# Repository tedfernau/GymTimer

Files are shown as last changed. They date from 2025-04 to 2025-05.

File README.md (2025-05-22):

A simple timer with a button and a vibration motor. 

I was thinking of this as a way to time intervals during workouts, or for phone-free timing in the sauna.

I designed it for a belt holder, but then I realized I would never let anyone see this in public!

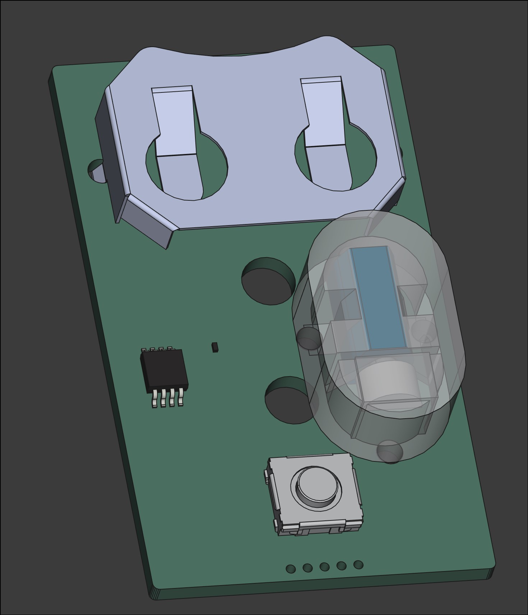
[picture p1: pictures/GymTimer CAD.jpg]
GymTimer GymTimer in FreeCAD


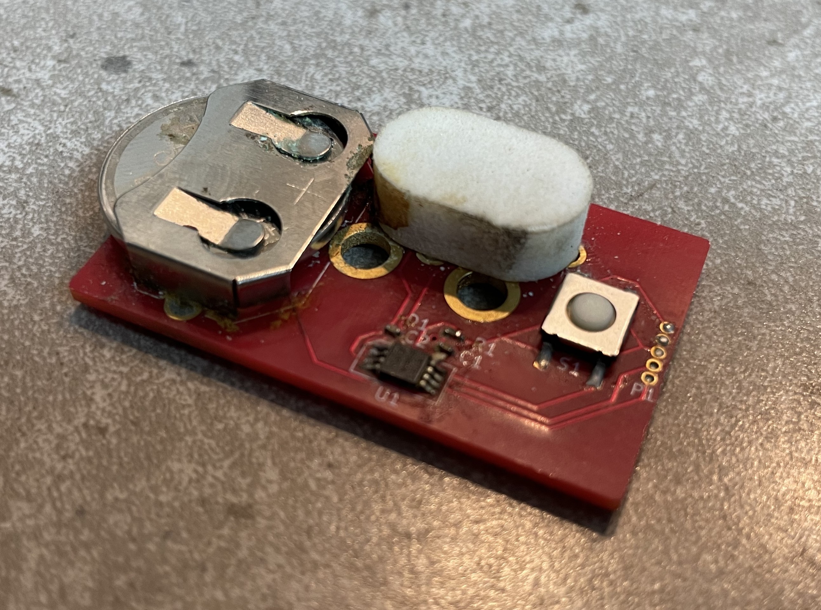
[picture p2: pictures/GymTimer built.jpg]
GymTimer GymTimer in FreeCAD


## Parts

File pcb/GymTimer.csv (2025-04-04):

Source: | C:\Users\fernau\OneDrive - F5, Inc\Desktop\LunchTimeProjects\GymTimer\GymTimer\pcb\GymTimer.kicad_sch
Date: | 5/27/2022 10:11:42 AM
Tool: | Eeschema (6.99.0-1656-g034b57d9c0)
Generator: | C:\Program Files\KiCad\6.99\bin\scripting\plugins/bom_csv_grouped_by_value.py
Component Count: | 8
Individual Components:
Item | Qty | Reference(s) | Value | LibPart | Footprint | Datasheet | Manufacturer Part Number
 |  | BT1 | BK-913 | GymTimer:BK-913 | GymTimer:BK-913 | https://www.digikey.com/en/products/detail/mpd-memory-protection-devices/BK-913/2329371
 |  | C1 | .1uF | Generic_Symbols:Capacitor | generic_footprints:cap-0402 | https://www.digikey.com/en/products/detail/kemet/C0402C104K4RACAUTO/3314827 | C0402C104K4RACAUTO
 |  | C2 | .1uF | Generic_Symbols:Capacitor | generic_footprints:cap-0402 | https://www.digikey.com/en/products/detail/kemet/C0402C104K4RACAUTO/3314827 | C0402C104K4RACAUTO
 |  | D1 | diode_TVS_bidirectional | Generic_Symbols:diode_TVS_bidirectional | GymTimer:TVS - PESD4V0Y1BSFYL | https://www.digikey.com/en/products/detail/nexperia-usa-inc/PESD4V0Y1BSFYL/9326494
 |  | M1 | VibrationDCmotor | GymTimer:VibrationDCmotor | GymTimer:Z4TH7B2120042P
 |  | R1 | 10k | Generic_Symbols:Resistor | generic_footprints:res_0402 | https://www.digikey.com/en/products/detail/koa-speer-electronics-inc/RK73G1ETTP1002F/9852052
 |  | S1 | SPST_NO_4pin | Generic_Symbols:SPST_NO_4pin | GymTimer:SPST-NO-EVQ-Q2U02W | https://www.digikey.com/en/products/detail/panasonic-electronic-components/EVQ-Q2U02W/762904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
 |  | U1 | PIC12F1571 | GymTimer:PIC12F1571 | GymTimer:PIC12F1571 MSOP8 | https://www.digikey.com/en/products/detail/microchip-technology/PIC12F1571-I-MS/4739306
Collated Components:
Item | Qty | Reference(s) | Value | LibPart | Footprint | Datasheet | Manufacturer Part Number
1 | 1 | BT1 | BK-913 | GymTimer:BK-913 | GymTimer:BK-913 | https://www.digikey.com/en/products/detail/mpd-memory-protection-devices/BK-913/2329371
2 | 2 | C1, C2 | .1uF | Generic_Symbols:Capacitor | generic_footprints:cap-0402 | https://www.digikey.com/en/products/detail/kemet/C0402C104K4RACAUTO/3314827 | C0402C104K4RACAUTO
3 | 1 | D1 | diode_TVS_bidirectional | Generic_Symbols:diode_TVS_bidirectional | GymTimer:TVS - PESD4V0Y1BSFYL | https://www.digikey.com/en/products/detail/nexperia-usa-inc/PESD4V0Y1BSFYL/9326494
4 | 1 | M1 | VibrationDCmotor | GymTimer:VibrationDCmotor | GymTimer:Z4TH7B2120042P
5 | 1 | R1 | 10k | Generic_Symbols:Resistor | generic_footprints:res_0402 | https://www.digikey.com/en/products/detail/koa-speer-electronics-inc/RK73G1ETTP1002F/9852052
6 | 1 | S1 | SPST_NO_4pin | Generic_Symbols:SPST_NO_4pin | GymTimer:SPST-NO-EVQ-Q2U02W | https://www.digikey.com/en/products/detail/panasonic-electronic-components/EVQ-Q2U02W/762904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
7 | 1 | U1 | PIC12F1571 | GymTimer:PIC12F1571 | GymTimer:PIC12F1571 MSOP8 | https://www.digikey.com/en/products/detail/microchip-technology/PIC12F1571-I-MS/4739306

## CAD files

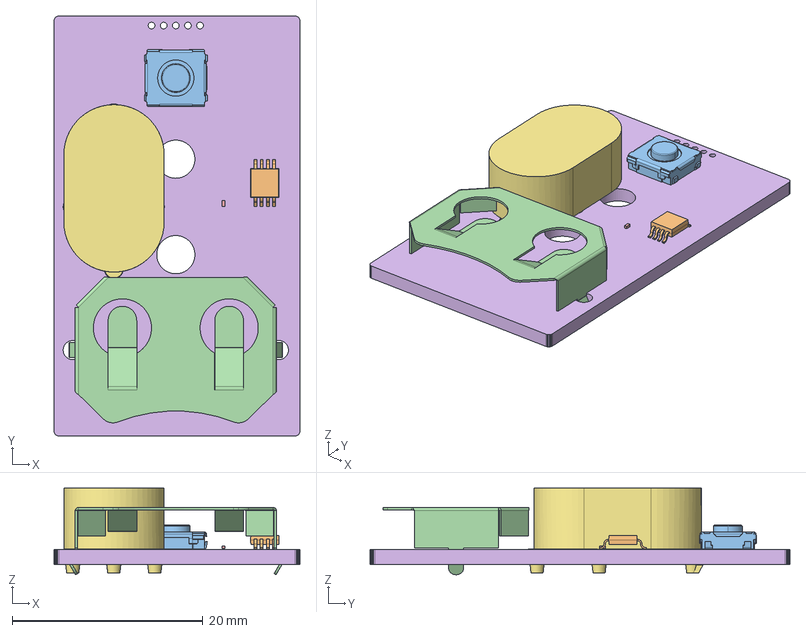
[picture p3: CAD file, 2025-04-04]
mechanical/Gymtimer.FCStd
25.8 x 44.0 x 9.07 mm
PCB

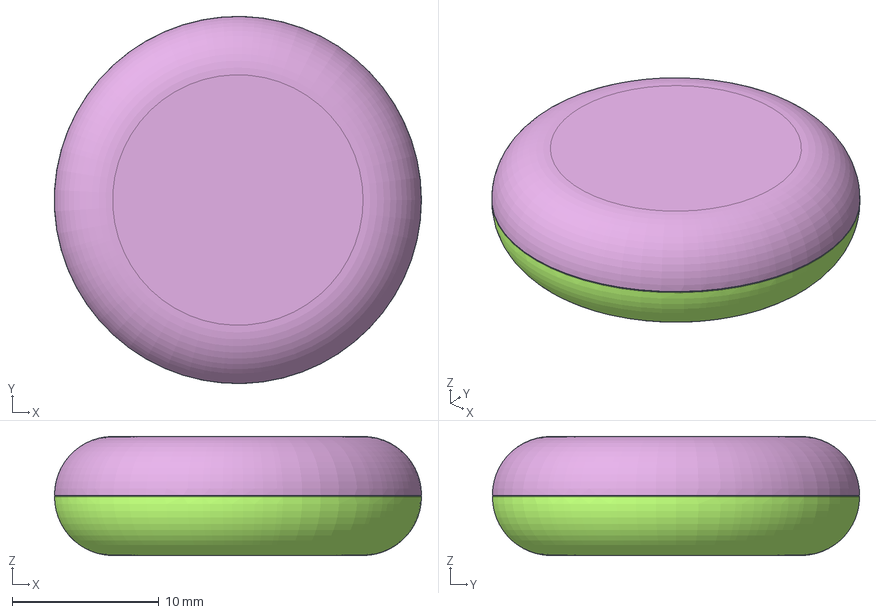
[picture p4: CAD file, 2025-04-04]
mechanical/Gymtimer2.FCStd
25.0 x 25.0 x 8.11 mm
Top
Bottom
battery
PCB

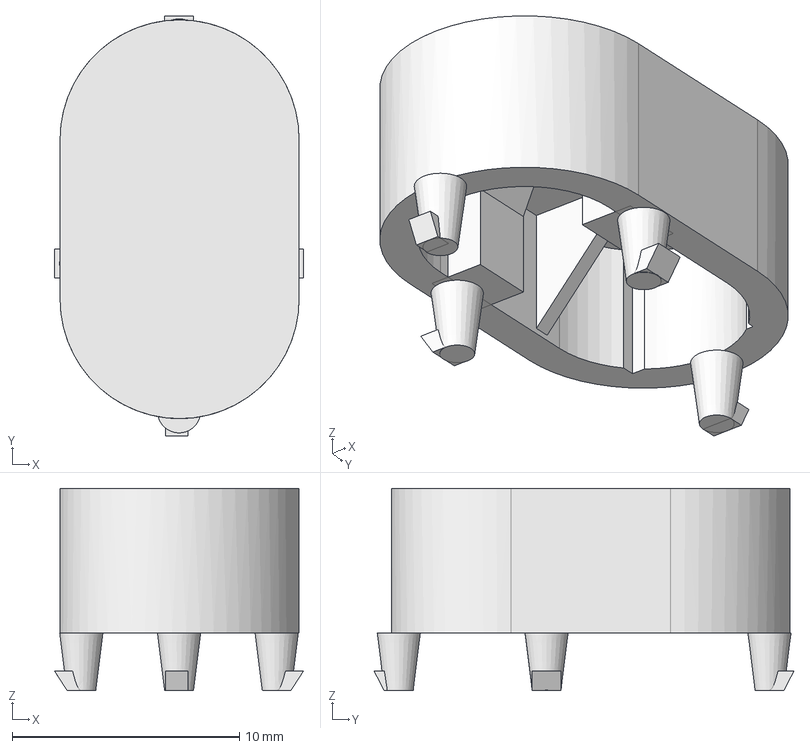
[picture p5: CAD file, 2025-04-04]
mechanical/Gymtimer-BodyPad005.step
11.0 x 18.5 x 8.89 mm

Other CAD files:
mechanical/Gymtimer-Body.step

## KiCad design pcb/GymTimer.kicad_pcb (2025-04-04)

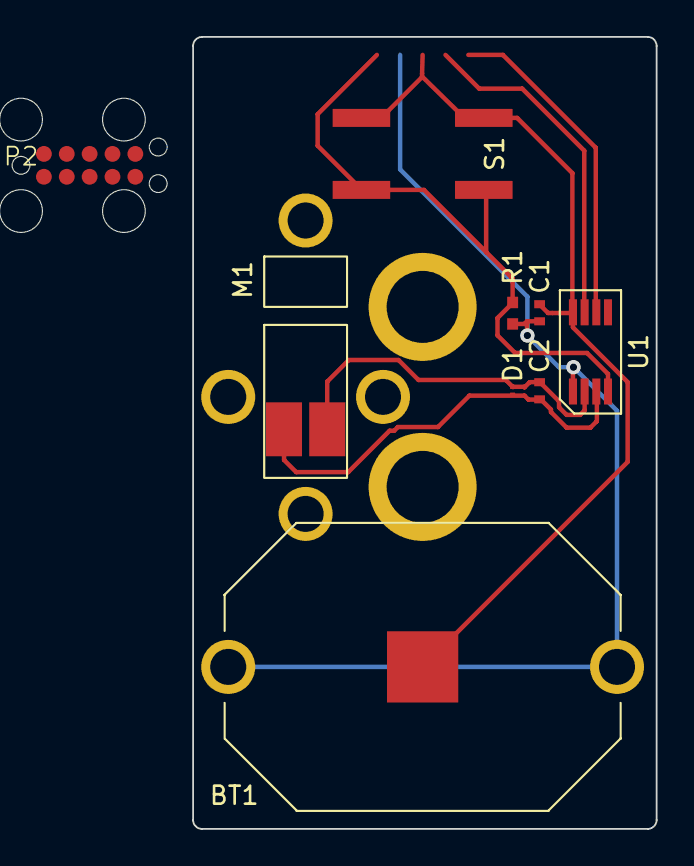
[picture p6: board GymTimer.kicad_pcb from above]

Board: 2 copper layers, 25.8 x 44.0 mm, 9 parts (0 on the bottom side), 8 nets.

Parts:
BT1: 3; BK-913
C1, C2: .1uF; cap-0402
D1: diode_TVS_bidirectional; TVS - PESD4V0Y1BSFYL
M1: VibrationDCmotor; Z4TH7B2120042P
P2: PICprogrammingheader; TC2050-idc
R1: 10k; res_0402
S1: SPST_NO_4pin; SPST-NO-EVQ-Q2U02W
U1: PIC12F1571; PIC12F1571 MSOP8

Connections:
3V: BT1.1 (+), C1.1, P2.7 (VDD), R1.1, U1.1 (VDD)
GND: BT1.2 (-), C1.2, P2.5 (GND), S1.1 (A), S1.2 (A), U1.8 (VSS)
unnamed: C2.1, D1.2
unnamed: C2.2, D1.1
unnamed: M1.1 (+), U1.2 (RA5)
unnamed: M1.2 (-), U1.3 (RA4)
unnamed: P2.9 (MCLR_N), R1.2, S1.3 (B), S1.4 (B), U1.4 (RA3/MCLR/VPP)
unnamed: P2.3 (PGD), U1.7 (RA0/ICSPDAT)

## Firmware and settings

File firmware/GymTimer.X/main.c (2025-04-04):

/**
  Generated Main Source File

  Company:
    Microchip Technology Inc.

  File Name:
    main.c

  Summary:
    This is the main file generated using PIC10 / PIC12 / PIC16 / PIC18 MCUs

  Description:
    This header file provides implementations for driver APIs for all modules selected in the GUI.
    Generation Information :
        Product Revision  :  PIC10 / PIC12 / PIC16 / PIC18 MCUs - 1.78
        Device            :  PIC12F1571
        Driver Version    :  2.00
*/

/*
    (c) 2018 Microchip Technology Inc. and its subsidiaries. 
    
    Subject to your compliance with these terms, you may use Microchip software and any 
    derivatives exclusively with Microchip products. It is your responsibility to comply with third party 
    license terms applicable to your use of third party software (including open source software) that 
    may accompany Microchip software.
    
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
    IN NO EVENT WILL MICROCHIP BE LIABLE FOR ANY INDIRECT, SPECIAL, PUNITIVE, 
    INCIDENTAL OR CONSEQUENTIAL LOSS, DAMAGE, COST OR EXPENSE OF ANY KIND 
    WHATSOEVER RELATED TO THE SOFTWARE, HOWEVER CAUSED, EVEN IF MICROCHIP 
    HAS BEEN ADVISED OF THE POSSIBILITY OR THE DAMAGES ARE FORESEEABLE. TO 
    THE FULLEST EXTENT ALLOWED BY LAW, MICROCHIP'S TOTAL LIABILITY ON ALL 
    CLAIMS IN ANY WAY RELATED TO THIS SOFTWARE WILL NOT EXCEED THE AMOUNT 
    OF FEES, IF ANY, THAT YOU HAVE PAID DIRECTLY TO MICROCHIP FOR THIS 
    SOFTWARE.
*/

#include "mcc_generated_files/mcc.h"

#define CALIBRATED_MINUTE_DELAY_VALUE   55101// was 54091 //was 59500
/*
                         Main application
 */
void main(void)
{
    // initialize the device
    SYSTEM_Initialize();

    uint16_t    readWord;
    //uint16_t    flashAddr = 0x01C0;
    uint16_t    flashAddr = 0x0380;
    uint16_t    Buf[ERASE_FLASH_BLOCKSIZE];
    
    
    readWord = FLASH_ReadWord(flashAddr);  
    
    
    if((readWord > 0x0000) && (readWord < 0x0005))
    {
        readWord = readWord + 0x0001;
        FLASH_WriteWord(flashAddr, Buf, readWord);
    }
    else
    {
        readWord = 0x0001;
        FLASH_WriteWord(flashAddr, Buf, readWord); 
    }
    while (1)
    {
    switch ( readWord )    
    {
        case 0x0000:
            ;
            uint8_t i = 0;
            while (i <= 10)
            {
                __delay_ms(100);

                IO_RA4_SetLow();
                IO_RA5_SetHigh();
                
                __delay_ms(100);

                
              IO_RA4_SetHigh();
              IO_RA5_SetHigh();
                i++;
            }

          SLEEP();
          break;
          
            case 1: //30sec - working out
            IO_RA4_SetLow();
            IO_RA5_SetHigh();  
            __delay_ms(50);
          IO_RA4_SetHigh();
          IO_RA5_SetHigh();
          
            __delay_ms(100);  
            
          IO_RA4_SetLow();
            IO_RA5_SetHigh();  
            __delay_ms(50);
          IO_RA4_SetHigh();
          IO_RA5_SetHigh();
          
          __delay_ms(100);  
            
          IO_RA4_SetLow();
            IO_RA5_SetHigh();  
            __delay_ms(50);
          IO_RA4_SetHigh();
          IO_RA5_SetHigh();
          
          __delay_ms(CALIBRATED_MINUTE_DELAY_VALUE/2);
          break;
        case 2: //2min - lifting
                IO_RA4_SetLow();
                IO_RA5_SetHigh();  
                __delay_ms(100);
              IO_RA4_SetHigh();
              IO_RA5_SetHigh();
                __delay_ms(100);              
              IO_RA4_SetLow();
                IO_RA5_SetHigh();  
                __delay_ms(100);
              IO_RA4_SetHigh();
              IO_RA5_SetHigh();
              __delay_ms(CALIBRATED_MINUTE_DELAY_VALUE*1.5);
          break;
        case 3: //10min - warm up
                IO_RA4_SetLow();
                IO_RA5_SetHigh();  
                __delay_ms(250);
              IO_RA4_SetHigh();
              IO_RA5_SetHigh();

              __delay_ms(CALIBRATED_MINUTE_DELAY_VALUE*8);
          break;
        case 4: //30min - sauna
                IO_RA4_SetLow();
                IO_RA5_SetHigh();  
                __delay_ms(250);
              IO_RA4_SetHigh();
              IO_RA5_SetHigh();
              
                __delay_ms(100);
                
                IO_RA4_SetLow();
                IO_RA5_SetHigh();  
                __delay_ms(250);
              IO_RA4_SetHigh();
              IO_RA5_SetHigh();
              
                __delay_ms(100);
                
                IO_RA4_SetLow();
                IO_RA5_SetHigh();  
                __delay_ms(100);
              IO_RA4_SetHigh();
              IO_RA5_SetHigh();
              
              __delay_ms(CALIBRATED_MINUTE_DELAY_VALUE*20);
          break;
        case 5: //1hr - sauna
                IO_RA4_SetLow();
                IO_RA5_SetHigh();  
                __delay_ms(500);
              IO_RA4_SetHigh();
              IO_RA5_SetHigh();

              __delay_ms(CALIBRATED_MINUTE_DELAY_VALUE*30);
          break;
//        case 5:
//                IO_RA4_SetLow();
//                IO_RA5_SetHigh();  
//                __delay_ms(100);
//              IO_RA4_SetHigh();
//              IO_RA5_SetHigh();
//                __delay_ms(100);
//                IO_RA4_SetLow();
//                IO_RA5_SetHigh();  
//                __delay_ms(100);
//              IO_RA4_SetHigh();
//              IO_RA5_SetHigh();
//                __delay_ms(100);
//                IO_RA4_SetLow();
//                IO_RA5_SetHigh();  
//                __delay_ms(100);
//              IO_RA4_SetHigh();
//              IO_RA5_SetHigh();
//                __delay_ms(100);
//                IO_RA4_SetLow();
//                IO_RA5_SetHigh();  
//                __delay_ms(100);
//              IO_RA4_SetHigh();
//              IO_RA5_SetHigh();
//                __delay_ms(100);
//                IO_RA4_SetLow();
//                IO_RA5_SetHigh();  
//                __delay_ms(100);
//              IO_RA4_SetHigh();
//              IO_RA5_SetHigh();
//          break;
        default:
          break;
    }

        


    if(readWord >= 0x0001)
        {
            readWord = readWord - 1;
            FLASH_WriteWord(flashAddr, Buf, readWord);
        }
   }
}
/**
 End of File
*/

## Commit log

2025-04-04 add GymTimer files to Github
    [GymTimer-B_Cu.gbr, GymTimer-B_Mask.gbr, GymTimer-Edge_Cuts.gbr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]
2025-04-04 add picture
    [Gymtimer.FCStd]
